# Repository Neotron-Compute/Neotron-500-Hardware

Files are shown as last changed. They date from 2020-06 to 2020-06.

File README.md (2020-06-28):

# Neotron 500

> A Neotron based home computer, powered by an 32-bit ARM Cortex-M7, with USB, Ethernet and hardware accelerated graphics.

## The top-level Specs

* 480 MHz 32-bit ARM Cortex-M7 CPU core
* 1024 KiB of internal ECC SRAM (used as VRAM and for OS buffers)
* 8 MiB external QuadSPI SRAM
* Super-VGA output
   * 640x480
   * 800x600
   * 256 colours from a pallette of 262,144
* 16-bit 48 kHz audio input and output (line-in, mic-in, line-out and headphone-out)
* Four high-speed (480 Mbps) USB 2.0 ports
   * Two USB A ports on-board
   * Header for additional two ports
* IEEE-1284 Parallel Port
* RS232 Port (five-wire)
* SD/MMC Slot
* PS/2 Keyboard and Mouse ports
* 2x Atari/Sega joystick ports
* IDE Interface for hard drive, Zip drive, LS-120 or CD-ROM
* Battery-backed Real-time Clock and CMOS RAM
* SPI and I2C based expansion bus

## Why 500?

We already had a Neotron 32 and a Neotron 1000, and this was somewhere inbetween the two. Plus it's roughly the performance of an Amiga 500.

## The detailed specs

### The Processor

The Neotron-500 uses an [STM32H753IIT6] microcontroller.

[STM32H753IIT6]: https://www.st.com/en/microcontrollers-microprocessors/stm32h753ii.html

```
STM32H753IIT6
vvvvv||vv|||+-- -40°C to +85°C
  |  ||| ||+-- LQFP Package
  |  ||| |+-- 2048 KiB Flash
  |  ||| +-- 176 pin
  |  ||+-- USB OTG FS/HS, Ethernet, LCD-TFT, Crypto
  |  |+-- Cortex-M7
  |  +-- High-performance family
  +-- 32-bit ARM Microcontroller from ST Micro
```

This microcontroller has:

* An ARM Cortex-M7F core
  * dual-issue, six-stage pipeline
  * hardware floating point
  * 16 KiB instruction cache
  * 16 KiB data cache  
* Clockspeed of up to 480 MHz
* 176 pins, in a low-profile quad flat package (LQFP)
* 2 MiB Flash
* 128 KiB tightly-coupled (Cortex-M only) data SRAM
* 64 KiB tightly-coupled (Cortex-M only) instruction SRAM
* 512 KiB of AXI-SRAM with ECC
* Further ECC SRAM banks of 128, 128, 64 and 32 KiB each
* 4 KiB of battery-backed SRAM
* External parallel memory bus interface with SDRAM support
* Memory-mapped 133 MHz QuadSPI interface
* MII/RMII 10/100 Ethernet MAC
* USB Full-speed (12 Mbps) OTG MAC/PHY
* USB High-speed (480 Mbps) OTG MAC
* 24-bit LCD-TFT interface with ChromART 2D video accelerator
* Hardware JPEG, random number generator, CRC and crypto
* RTC with 4 KiB battery backed RAM
* MIPI CSI Camera interface
* 2x SD/MMC controllers
* Multiple I2S audio in/out interfaces
* Multiple UART interfaces
* Multiple SPI bus interfaces
* Multiple I2C bus interfaces
* Multiple CAN bus interfaces

In terms of the CoreMark benchmark (and when running from internal Flash), this CPU is about the same speed as a Raspberry Pi Zero (despite running at just 40% of the clock speed), and somewhere around an 866 MHz Pentium III running from SDRAM. Running from external QuadSPI SRAM, however, is where we are down on performance. PC66 SDRAM has a peak of around 500 MiB/sec, and 32-bit 33.3 MHz DRAM is about 125 MiB/sec, whilst our QuadSPI SRAM is more like 40 MiB/sec. But I'm hoping it will run Doom.

### Memory Layout

We use:

* 128 KiB tightly-coupled data SRAM for the system stack and OS buffer.
* 64 KiB tightly-coupled instruction SRAM for OS routines.
* 128 KiB SRAM for DMA and device buffers.
* 512 KiB AXI-SRAM for video frame buffers.
  * 640x480 @ 8bpp = 300 KiB
  * 800x600 @ 8bpp = 468 KiB
* 4 KiB battery backed SRAM for system settings
* 512 KiB internal Flash for the Neotron BIOS
* 512 KiB internal Flash for Neotron OS
* 1024 KiB internal Flash for ROM-based user applications

You can either use external QSPI SRAM, or the second 128 KiB SRAM bank, for running user applications.

## The Motherboard

The Neotron 500 Motherboard is completely open-source hardware, and all the components are either through-hole parts that are easy to self install, or available from the [JLCPCB SMT assembly service].

The motherboard has:

* Regulated 5V Input
  * If you want to power four 500 mA USB devices from your Neotron 528ST, this needs to be capable at least 2.5A
  * TBD whether this is a DC barrel jack, full-size USB B, mini USB B or micro USB B
  * Or even take 5V from a 110V/240V IEC inlet PSU
  * Or we could take 6V-9V from a DC barrel jack and have an on-board 5V regulator
* Lyontek LY68L6400SLIT 8 MiB (8Mbit x 8) QuadSPI SRAM
  * 4-bit interface
  * 84 MHz clock rate (higher if we can configure the STM32 to avoid crossing page boundaries)
* Texas Instruments DP83848C 10/100 MII/RMII Ethernet PHY, and RJ45 Ethernet jack
  * MII Interface to the STM32
  * RJ45 100BASE-TX Ethernet jack
* Texas Instruments TLV320AIC23BPW Audio Codec
  * 16-bit 48 kHz I2S input and output to the STM32
  * Amplified stereo 3.5mm TRS headphone output
  * Line-level stereo 3.5mm TRS output
  * Line-level stereo 3.5mm TRS input
  * Mono microphone 3.5mm input
* Microchip USB3300 High-speed (480 Mbps) ULPI USB 2.0 PHY
* Microchip USB2514B High-speed (480 Mbps) four port USB 2.0 hub, with 2x2 USB 2.0 A ports.
* 18-bit (6-6-6) R2R DAC and 3PEAK HD video output buffer, with standard DE15HD VGA connector
* Full-size external-facing SD Card slot
* 2x PS/2 Ports for keyboard and mouse (2x mini-DIN 6-pin sockets)
* 2x 9-pin Atari Joystick/SEGA Genesis game-pad ports
* Power switch and reset switch
* MIDI In and Out ports (2x 5-pin DIN180 sockets)
* IEEE1284 Parallel Port (26-pin IDC box header as used on PCs)
* RS232 Port (five-wire, 10-pin IDC box header as used on PCs)
* 40-pin IDE interface
* Coin-cell for the STM32's real-time clock and battery-backed SRAM
* SPI and I2C based expansion bus (compatible with the Neotron 32)
* Additional QuadSPI expansion bus

[JLCPCB SMT assembly service]: https://jlcpcb.com/parts

Expected price is $40 for the motherboard with SMT parts loaded, and another $20 for the through-hole connectors

## Software

This system is designed to run the Neotron OS. To do that, it has a bespoke version of the Neotron BIOS. It is compatible with all 'well-behaved' Neotron applications that stick to the Neotron OS APIs rather than poking hardware directly.

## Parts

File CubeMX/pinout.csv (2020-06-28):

Position | Name | Type | Signal | Label
1 | PE2 | I/O | FMC_A23
2 | PE3 | I/O | FMC_A19
3 | PE4 | I/O | FMC_A20
4 | PE5 | I/O | FMC_A21
5 | PE6 | I/O | FMC_A22
6 | VBAT | Power
7 | PI8 | I/O
8 | PC13 | I/O
9 | PC14 | I/O | RCC_OSC32_IN
10 | PC15 | I/O | RCC_OSC32_OUT
11 | PI9 | I/O | LTDC_VSYNC
12 | PI10 | I/O | LTDC_HSYNC
13 | PI11 | I/O | USB_OTG_HS_ULPI_DIR
14 | VSS | Power
15 | VDD | Power
16 | PF0 | I/O | FMC_A0
17 | PF1 | I/O | FMC_A1
18 | PF2 | I/O | FMC_A2
19 | PF3 | I/O | FMC_A3
20 | PF4 | I/O | FMC_A4
21 | PF5 | I/O | FMC_A5
22 | VSS | Power
23 | VDD | Power
24 | PF6 | I/O | QUADSPI_BK1_IO3
25 | PF7 | I/O | QUADSPI_BK1_IO2
26 | PF8 | I/O | QUADSPI_BK1_IO0
27 | PF9 | I/O | QUADSPI_BK1_IO1
28 | PF10 | I/O | LTDC_DE
29 | PH0 | I/O | RCC_OSC_IN
30 | PH1 | I/O | RCC_OSC_OUT
31 | NRST | Reset
32 | PC0 | I/O | USB_OTG_HS_ULPI_STP
33 | PC1 | I/O | ETH_MDC
34 | PC2_C | I/O | I2S2_SDI
35 | PC3_C | I/O | USB_OTG_HS_ULPI_NXT
36 | VDD | Power
37 | VSSA | Power
38 | VREF+ | MonoIO
39 | VDDA | Power
40 | PA0 | I/O | SDMMC2_CMD
41 | PA1 | I/O | ETH_REF_CLK
42 | PA2 | I/O | ETH_MDIO
43 | PH2 | I/O | QUADSPI_BK2_IO0
44 | PH3 | I/O | QUADSPI_BK2_IO1
45 | PH4 | I/O | LTDC_G5
46 | PH5 | I/O
47 | PA3 | I/O | USB_OTG_HS_ULPI_D0
48 | VSS | Power
49 | VDD | Power
50 | PA4 | I/O | USB_OTG_HS_SOF
51 | PA5 | I/O | USB_OTG_HS_ULPI_CK
52 | PA6 | I/O | MDIOS_MDC
53 | PA7 | I/O | ETH_CRS_DV
54 | PC4 | I/O | ETH_RXD0
55 | PC5 | I/O | ETH_RXD1
56 | PB0 | I/O | USB_OTG_HS_ULPI_D1
57 | PB1 | I/O | USB_OTG_HS_ULPI_D2
58 | PB2 | I/O | QUADSPI_CLK
59 | PF11 | I/O | SPI5_MOSI
60 | PF12 | I/O | FMC_A6
61 | VSS | Power
62 | VDD | Power
63 | PF13 | I/O | FMC_A7
64 | PF14 | I/O | FMC_A8
65 | PF15 | I/O | FMC_A9
66 | PG0 | I/O | FMC_A10
67 | PG1 | I/O | FMC_A11
68 | PE7 | I/O | FMC_D4
69 | PE8 | I/O | FMC_D5
70 | PE9 | I/O | FMC_D6
71 | VSS | Power
72 | VDD | Power
73 | PE10 | I/O | FMC_D7
74 | PE11 | I/O | FMC_D8
75 | PE12 | I/O | FMC_D9
76 | PE13 | I/O | FMC_D10
77 | PE14 | I/O | FMC_D11
78 | PE15 | I/O | FMC_D12
79 | PB10 | I/O | USB_OTG_HS_ULPI_D3
80 | PB11 | I/O | USB_OTG_HS_ULPI_D4
81 | VCAP | Power
82 | VDD | Power
83 | PH6 | I/O | SPI5_SCK
84 | PH7 | I/O | SPI5_MISO
85 | PH8 | I/O | LTDC_R2
86 | PH9 | I/O | LTDC_R3
87 | PH10 | I/O | LTDC_R4
88 | PH11 | I/O | LTDC_R5
89 | PH12 | I/O | LTDC_R6
90 | VSS | Power
91 | VDD | Power
92 | PB12 | I/O | USB_OTG_HS_ULPI_D5
93 | PB13 | I/O | USB_OTG_HS_ULPI_D6
94 | PB14 | I/O | SDMMC2_D0
95 | PB15 | I/O | SDMMC2_D1
96 | PD8 | I/O | FMC_D13
97 | PD9 | I/O | FMC_D14
98 | PD10 | I/O | FMC_D15
99 | PD11 | I/O | FMC_A16
100 | PD12 | I/O | FMC_A17
101 | PD13 | I/O | FMC_A18
102 | VSS | Power
103 | VDD | Power
104 | PD14 | I/O | FMC_D0
105 | PD15 | I/O | FMC_D1
106 | PG2 | I/O | FMC_A12
107 | PG3 | I/O | FMC_A13
108 | PG4 | I/O | FMC_A14
109 | PG5 | I/O | FMC_A15
110 | PG6 | I/O | LTDC_R7
111 | PG7 | I/O | LTDC_CLK
112 | PG8 | I/O | LTDC_G7
113 | VSS | Power
114 | VDD33_USB | Power
115 | PC6 | I/O | I2S2_MCK
116 | PC7 | I/O | FMC_NE1
117 | PC8 | I/O | UART5_RTS
118 | PC9 | I/O | UART5_CTS
119 | PA8 | I/O | LTDC_B3
120 | PA9 | I/O | I2S2_CK
121 | PA10 | I/O | MDIOS_MDIO
122 | PA11 | I/O | USB_OTG_FS_DM
123 | PA12 | I/O | USB_OTG_FS_DP
124 | PA13 | I/O | DEBUG_JTMS-SWDIO
125 | VCAP | Power
126 | VSS | Power
127 | VDD | Power
128 | PH13 | I/O | LTDC_G2
129 | PH14 | I/O | LTDC_G3
130 | PH15 | I/O | LTDC_G4
131 | PI0 | I/O
132 | PI1 | I/O | LTDC_G6
133 | PI2 | I/O
134 | PI3 | I/O | I2S2_SDO
135 | VSS | Power
136 | VDD | Power
137 | PA14 | I/O | DEBUG_JTCK-SWCLK
138 | PA15 | I/O
139 | PC10 | I/O
140 | PC11 | I/O | QUADSPI_BK2_NCS
141 | PC12 | I/O | UART5_TX
142 | PD0 | I/O | FMC_D2
143 | PD1 | I/O | FMC_D3
144 | PD2 | I/O | UART5_RX
145 | PD3 | I/O
146 | PD4 | I/O | FMC_NOE
147 | PD5 | I/O | FMC_NWE
148 | VSS | Power
149 | VDD | Power
150 | PD6 | I/O | SDMMC2_CK
151 | PD7 | I/O
152 | PG9 | I/O | QUADSPI_BK2_IO2
153 | PG10 | I/O | LTDC_B2
154 | PG11 | I/O | ETH_TX_EN
155 | PG12 | I/O | ETH_TXD1
156 | PG13 | I/O | ETH_TXD0
157 | PG14 | I/O | QUADSPI_BK2_IO3
158 | VSS | Power
159 | VDD | Power
160 | PG15 | I/O
161 | PB3 | I/O | SDMMC2_D2
162 | PB4 | I/O | SDMMC2_D3
163 | PB5 | I/O | USB_OTG_HS_ULPI_D7
164 | PB6 | I/O | QUADSPI_BK1_NCS
165 | PB7 | I/O | I2C1_SDA
166 | BOOT0 | Boot
167 | PB8 | I/O | I2C1_SCL
168 | PB9 | I/O | I2S2_WS
169 | PE0 | I/O | FMC_NBL0
170 | PE1 | I/O | FMC_NBL1
171 | PDR_ON | Reset
172 | VDD | Power
173 | PI4 | I/O | LTDC_B4
174 | PI5 | I/O | LTDC_B5
175 | PI6 | I/O | LTDC_B6
176 | PI7 | I/O | LTDC_B7

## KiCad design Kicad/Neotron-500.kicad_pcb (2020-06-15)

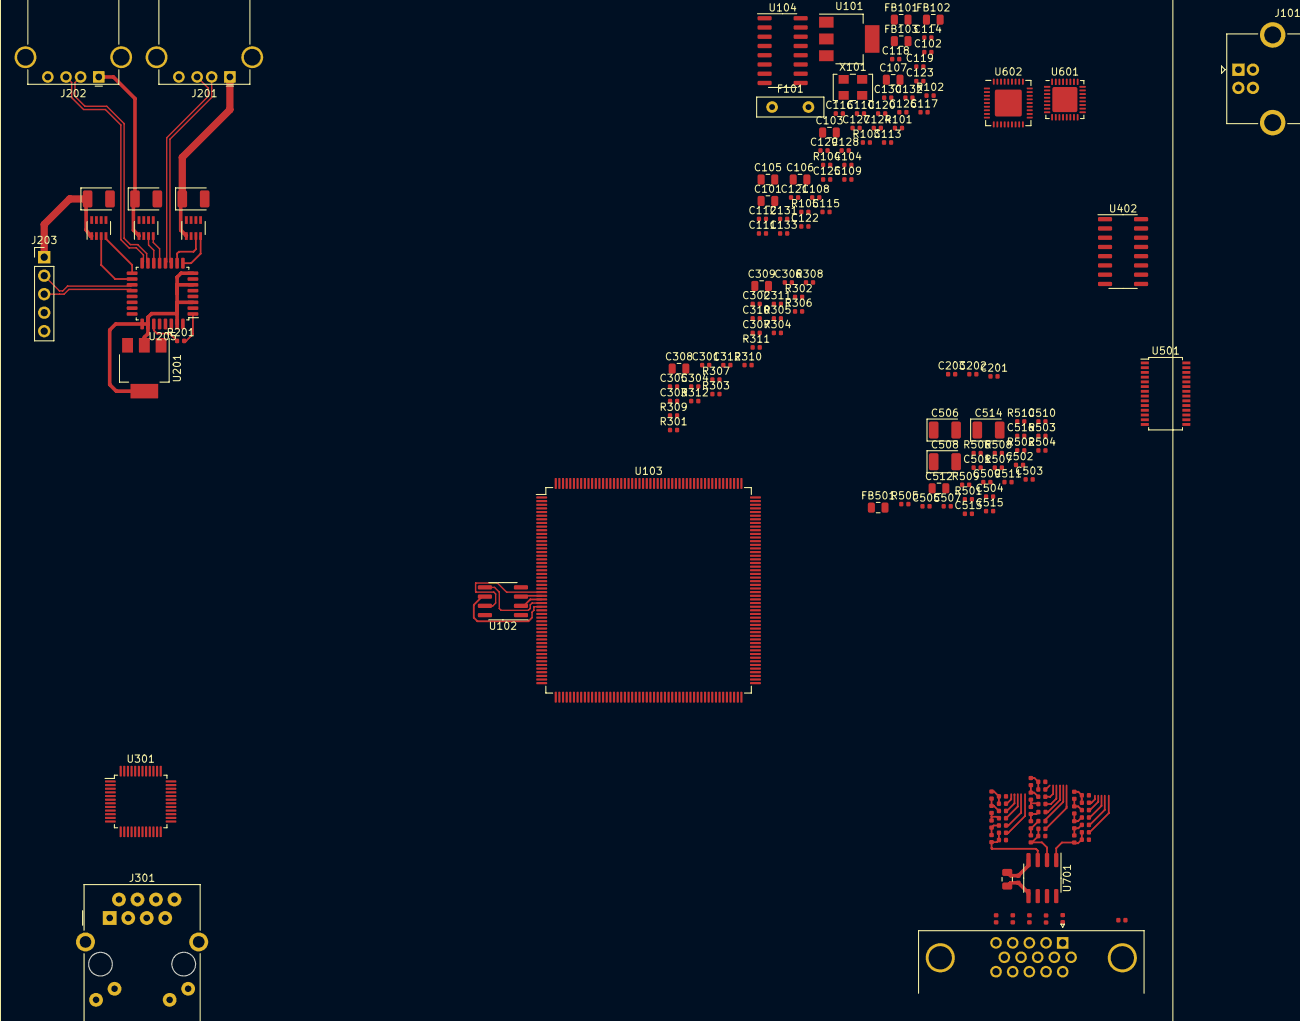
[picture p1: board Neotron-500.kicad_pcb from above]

Board: 2 copper layers, 165 parts (0 on the bottom side), 125 nets.

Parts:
C101, C103, C105: 22u; C_0805_2012Metric
C102, C104, C108, C113, C115, C117, C119, C120, C121, C122, C123, C124, C125, C126, C128, C129, C130, C131, C132, C133, C201, C301, C302, C303, C304, C305, C306, C307, C310, C311, C312, C511, C513, C702: 100n; C_0402_1005Metric
C106, C107: 2.2u; C_0805_2012Metric
C109, C110, C111, C112: 9p; C_0402_1005Metric
C114, C116, C118, C127, C501, C502, C504, C505, C509: 1u; C_0402_1005Metric
C202, C203: 4.7u; C_0402_1005Metric
C204, C205, C206, C506, C508, C514: 100u; CP_EIA-3528-21_Kemet-B
C308, C309, C512: 10u; C_0805_2012Metric
C503, C507, C510: 47p; C_0402_1005Metric
C515, C516: 27p; C_0402_1005Metric
C701: 4.7u; C_0805_2012Metric
F101: 2.5A; C_Disc_D9.0mm_W2.5mm_P5.00mm
FB101, FB102, FB103, FB501: 100R@100MHz; L_0805_2012Metric
J101: USB_B; USB_B_OST_USB-B1HSxx_Horizontal
J201, J202: USB_A; USB_A_Stewart_SS-52100-001_Horizontal
J203: USB_A; PinHeader_1x05_P2.54mm_Vertical
J301: RJ45_Amphenol_RJMG1BD3B8K1ANR
J701: DB15_Female_HighDensity_MountingHoles; DSUB-15-HD_Female_Horizontal_P2.29x1.98mm_EdgePinOffset3.03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
R101, R102, R103, R312: 0R; R_0402_1005Metric
R104, R105: 10k; R_0402_1005Metric
R201: 1.5k; R_0402_1005Metric
R301, R302, R305, R307: 49.9R; R_0402_1005Metric
R303, R304, R306, R310: 2k2; R_0402_1005Metric
R308, R309: 1k; R_0402_1005Metric
R311: 4.87K; R_0402_1005Metric
R501: 2.2k; R_0402_1005Metric
R502, R503, R506, R507: 100k; R_0402_1005Metric
R504, R508: 4.99k; R_0402_1005Metric
R505, R509: 5k; R_0402_1005Metric
R510: 3R3; R_0402_1005Metric
R701, R702, R703, R704, R705, R711, R717, R718, R719, R720, R721, R722, R729, R731, R732, R733, R734, R735, R740: 24K; R_0402_1005Metric
R706, R707, R708, R709, R724, R725, R726, R727, R728, R736, R737, R738, R739: 12K; R_0402_1005Metric
R710, R730, R741: 3K3; R_0402_1005Metric
R712, R713, R714: 75; R_0402_1005Metric
R715, R716: 470; R_0402_1005Metric
R723: 0; R_0402_1005Metric
U101, U201: AMS1117-3.3; SOT-223-3_TabPin2
U102: LY68S3200SLT; SOIC-8_3.9x4.9mm_P1.27mm
U103: STM32F767BGTx; LQFP-208_28x28mm_P0.5mm
U104: MAX232; SOIC-16_3.9x9.9mm_P1.27mm
U202, U203, U204: AAT4610BIGV-1-T1; SOT-23-8
U205: TUSB2036; LQFP-32_7x7mm_P0.8mm
U301: DP83848C; LQFP-48_7x7mm_P0.5mm
U402: 74LS138; SOIC-16_3.9x9.9mm_P1.27mm
U501: TLV320AIC23BPW; TSSOP-28_4.4x9.7mm_P0.65mm
U601: USB3300-EZK; QFN-32-1EP_5x5mm_P0.5mm_EP3.45x3.45mm
U602: USB2514B_Bi; QFN-36-1EP_6x6mm_P0.5mm_EP3.7x3.7mm
U701: TPF133A; SOIC-8_3.9x4.9mm_P1.27mm
X101: 50MHz XO; Oscillator_SMD_TXC_7C-4Pin_5.0x3.2mm

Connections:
+3V3: C108.1, C301.1, C302.1, C303.1, C304.1, C511.1, C512.1, C701.1, C702.1, FB501.1, J301.R4, J301.R5, R301.2, R302.1, R305.2, R306.1, R307.1, R308.2, R309.2, R310.1, R312.2, U102.8, U301.22, U301.32, U301.48, U501.1, U501.22, U501.27, U701.4, X101.1, X101.4
+5V: C101.1, C104.1, C105.1, C201.1, C202.1, F101.1, U101.3, U201.3, U202.5, U203.5, U204.5
/Audio/HEADPHONE_L: C506.1, U501.9
/Audio/HEADPHONE_R: C508.1, U501.10
/Audio/LINE_IN_L: C505.1, U501.20
/Audio/LINE_IN_R: C509.1, U501.19
/Audio/LINE_OUT_L: C502.1, U501.12
/Audio/LINE_OUT_R: C504.1, U501.13
/Audio/MIC_IN: C501.1, U501.18
/Audio/VDD_AUDIO: C513.1, C514.1, FB501.2, R510.2, U501.8
/Audio/V_MICBIAS: R501.1, U501.17
/Ethernet PHY/LED_ACT: J301.L2, U301.26
/Ethernet PHY/LED_SPEED: J301.L3, U301.27
/LTDC_B3: R731.1, U103.110
/LTDC_B4: R732.1, U103.144
/LTDC_B5: R733.1, U103.187
/LTDC_B6: R734.1, U103.188
/LTDC_B7: R735.1, U103.189
/LTDC_G2: R717.1, U103.55
/LTDC_G3: R718.1, U103.85
/LTDC_G4: R719.1, U103.123
/LTDC_G5: R720.1, U103.126
/LTDC_G6: R721.1, U103.127
/LTDC_G7: R722.1, U103.128
/LTDC_HSYNC: R715.2, U103.12
/LTDC_R3: R701.1, U103.67
/LTDC_R4: R702.1, U103.68
/LTDC_R5: R703.1, U103.69
/LTDC_R6: R704.1, U103.95
/LTDC_R7: R705.1, U103.65
/LTDC_VSYNC: R716.2, U103.11
/QUADSPI_BK1_IO0: U102.2, U103.29
/QUADSPI_BK1_IO1: U102.5, U103.30
/QUADSPI_BK1_IO2: U102.3, U103.28
/QUADSPI_BK1_IO3: U102.7, U103.27
/QUADSPI_BK1_NCS: U102.1, U103.195
/QUADSPI_CLK: U102.6, U103.31
/RCC_OSC32_IN: C111.1, U103.9
/RCC_OSC32_OUT: C112.1, U103.10
/RCC_OSC_IN: C109.1, U103.32
/RCC_OSC_OUT: C110.1, U103.33
/USB 1.1 Host/HUB_3V3: C203.1, U201.2, U205.3, U205.6, U205.8, U205.25, U205.26, U205.31
/USB 1.1 Host/PORT1_D+: J201.3, U205.12
/USB 1.1 Host/PORT1_D-: J201.2, U205.11
/USB 1.1 Host/PORT2_D+: J202.3, U205.16
/USB 1.1 Host/PORT2_D-: J202.2, U205.15
/USB 1.1 Host/PORT3_D+: J203.3, U205.20
/USB 1.1 Host/PORT3_D-: J203.2, U205.19
/USB 1.1 Host/~PORT1_EN: U202.4, U205.9
/USB 1.1 Host/~PORT1_OC: U202.3, U205.10
/USB 1.1 Host/~PORT2_EN: U203.4, U205.13
/USB 1.1 Host/~PORT2_OC: U203.3, U205.14
/USB 1.1 Host/~PORT3_EN: U204.4, U205.17
/USB 1.1 Host/~PORT3_OC: U204.3, U205.18
/USB_OTG_HS_D+: R201.2, U205.1
/VDDA: C115.1, C116.1, FB101.2, R101.2, U103.42
/VDD_MCU: C102.1, C103.1, C119.1, C120.1, C121.1, C122.1, C123.1, C124.1, C125.1, C128.1, C129.1, C130.1, C131.1, C132.1, C133.1, FB101.1, R102.2, R103.2, U101.2, U103.15, U103.26, U103.39, U103.52, U103.59, U103.73, U103.83, U103.94, U103.103, U103.115, U103.124, U103.150, U103.158, U103.185, U103.204
/VDD_SDMMC: C126.1, C127.1, R102.1, U103.171
/VDD_USB: C117.1, C118.1, R103.1, U103.137
/VGA Video Output/ANALOG_BLUE: R735.2, R739.1, R741.1, U701.3
/VGA Video Output/ANALOG_GREEN: R722.2, R728.1, R730.1, U701.2
/VGA Video Output/ANALOG_RED: R705.2, R709.1, R710.1, U701.1
/VGA Video Output/BOUT: R714.1, U701.6
/VGA Video Output/GOUT: R713.1, U701.7
/VGA Video Output/ROUT: R712.1, U701.8
/VREF+: C113.1, C114.1, R101.1, U103.41
GND: C101.2, C102.2, C103.2, C104.2, C105.2, C106.2, C107.2, C108.2, C109.2, C110.2, C111.2, C112.2, C113.2, C114.2, C115.2, C116.2, C117.2, C118.2, C119.2, C120.2, C121.2, C122.2, C123.2, C124.2, C125.2, C126.2, C127.2, C128.2, C129.2, C130.2, C131.2, C132.2, C133.2, C201.2, C202.2, C203.2, C204.2, C205.2, C206.2, C301.2, C302.2, C303.2, C304.2, C305.2, C306.2, C307.2, C308.2, C309.2, C310.2, C311.2, C312.2, C511.2, C512.2, C513.2, C514.2, C515.2, C516.2, C701.2, C702.2, FB103.1, J101.4, J201.4, J201.5, J202.4, J202.5, J203.4, J203.5, J301.13, J301.R8, J701.5, J701.6, J701.7, J701.8, R104.2, R303.2, R304.2, R311.1, R710.2, R711.2, R723.2, R729.2, R730.2, R740.2, R741.2, U101.1, U102.4, U103.14, U103.25, U103.40, U103.51, U103.60, U103.72, U103.82, U103.93, U103.114, U103.125, U103.136, U103.149, U103.170, U103.184, U103.202, U201.1, U202.2, U203.2, U204.2, U205.7, U205.21, U205.22, U205.23, U205.24, U205.28, U301.15, U301.19, U301.35, U301.36, U301.47, U501.28, U701.5, X101.2
GNDA: C503.2, C507.2, C510.2, R502.1, R503.1, R505.1, R506.1, R507.1, R509.1, U501.11, U501.15
unnamed: C106.1, U103.92
unnamed: C107.1, U103.148
unnamed: C204.1, J201.1, U202.1
unnamed: C205.1, J202.1, U203.1
unnamed: C206.1, J203.1, U204.1
unnamed: C305.1, U301.37
unnamed: C306.1, U301.18
unnamed: C307.1, C308.1, U301.23
unnamed: C309.1, C310.1, C311.1, C312.1, R312.1
unnamed: C501.2, C503.1, R501.2
unnamed: C502.2, R502.2
unnamed: C504.2, R503.2
unnamed: C505.2, C507.1, R504.1, R505.2
unnamed: C506.2, R506.2
unnamed: C508.2, R507.2
unnamed: C509.2, C510.1, R508.1, R509.2
unnamed: C515.1, U501.25
unnamed: C516.1, U501.26
unnamed: F101.2, FB102.2
unnamed: FB102.1, J101.1
unnamed: FB103.2, J101.5
unnamed: J301.L1, R309.1
unnamed: J301.L4, R308.1
unnamed: J301.R1, R301.1, U301.17
unnamed: J301.R2, R302.2, U301.16
unnamed: J301.R3, R305.1, U301.14
unnamed: J301.R6, R307.2, U301.13
unnamed: J701.0, R723.1
unnamed: J701.1, R712.2
unnamed: J701.2, R713.2
unnamed: J701.3, R714.2
unnamed: J701.13, R715.1
unnamed: J701.14, R716.1
unnamed: R104.1, U103.203
unnamed: R105.1, U103.197
unnamed: R201.1, U205.27
unnamed: R303.1, U301.5
unnamed: R304.1, U301.6
unnamed: R306.2, U301.39
unnamed: R310.2, U301.7
unnamed: R311.2, U301.24
unnamed: R510.1, U501.14
unnamed: R701.2, R706.2, R711.1
unnamed: R702.2, R706.1, R707.2
unnamed: R703.2, R707.1, R708.2
unnamed: R704.2, R708.1, R709.2
unnamed: R717.2, R724.2, R729.1
unnamed: R718.2, R724.1, R725.2
unnamed: R719.2, R725.1, R726.2
unnamed: R720.2, R726.1, R727.2
unnamed: R721.2, R727.1, R728.2
unnamed: R731.2, R736.2, R740.1
unnamed: R732.2, R736.1, R737.2
unnamed: R733.2, R737.1, R738.2
unnamed: R734.2, R738.1, R739.2
unnamed: U601.7, U602.31
unnamed: U601.8, U602.30

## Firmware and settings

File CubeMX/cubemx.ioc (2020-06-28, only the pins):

PH12.Signal=LTDC_R6
PG4.Signal=FMC_A14_BA0
PG8.Signal=LTDC_G7
PC12.Signal=UART5_TX
PG0.Signal=FMC_A10
PB13.Signal=USB_OTG_HS_ULPI_D6
PG13.Signal=ETH_TXD0
PF7.Signal=QUADSPI_BK1_IO2
PH9.Signal=LTDC_R3
PD4.Signal=FMC_NOE
PB6.Signal=QUADSPI_BK1_NCS
PC7.Signal=FMC_NE1
PD0.Signal=FMC_D2_DA2
PD8.Signal=FMC_D13_DA13
PE5.Signal=FMC_A21
PE1.Signal=FMC_NBL1
PB2.Signal=QUADSPI_CLK
PE9.Signal=FMC_D6_DA6
PI6.Signal=LTDC_B6
PI3.Signal=I2S2_SDO
PE2.Signal=FMC_A23
PA8.Signal=LTDC_B3
PF3.Signal=FMC_A3
PE10.Signal=FMC_D7_DA7
PA0.Signal=SDMMC2_CMD
PB9.Signal=I2S2_WS
PB1.Signal=USB_OTG_HS_ULPI_D2
PD12.Signal=FMC_A17_ALE
PA10.Signal=MDIOS_MDIO
PH2.Signal=QUADSPI_BK2_IO0
PF14.Signal=FMC_A8
PI11.Signal=USB_OTG_HS_ULPI_DIR
PD15.Signal=FMC_D1_DA1
PG12.Signal=ETH_TXD1
PH15.Signal=LTDC_G4
PH13.Signal=LTDC_G2
PG5.Signal=FMC_A15_BA1
PG9.Signal=QUADSPI_BK2_IO2
PC6.Signal=I2S2_MCK
PD1.Signal=FMC_D3_DA3
PC0.Signal=USB_OTG_HS_ULPI_STP
PG10.Signal=LTDC_B2
PD10.Signal=FMC_D15_DA15
PA9.Signal=I2S2_CK
PB10.Signal=USB_OTG_HS_ULPI_D3
PB14.Signal=SDMMC2_D0
PA5.Signal=USB_OTG_HS_ULPI_CK
PI7.Signal=LTDC_B7
PE14.Signal=FMC_D11_DA11
PE15.Signal=FMC_D12_DA12
PE8.Signal=FMC_D5_DA5
PI1.Signal=LTDC_G6
PF13.Signal=FMC_A7
PA4.Signal=USB_OTG_HS_SOF
PB5.Signal=USB_OTG_HS_ULPI_D7
PD11.Signal=FMC_A16_CLE
PA11.Signal=USB_OTG_FS_DM
PH6.Signal=SPI5_SCK
PF9.Signal=QUADSPI_BK1_IO1
PE3.Signal=FMC_A19
PF4.Signal=FMC_A4
PD2.Signal=UART5_RX
PB0.Signal=USB_OTG_HS_ULPI_D1
PC1.Signal=ETH_MDC
PG6.Signal=LTDC_R7
Mcu.UserName=STM32H753IITx
PH14.Signal=LTDC_G3
PH10.Signal=LTDC_R4
PG2.Signal=FMC_A12
PB11.Signal=USB_OTG_HS_ULPI_D4
PB15.Signal=SDMMC2_D1
PG11.Signal=ETH_TX_EN
PD13.Signal=FMC_A18
PA12.Signal=USB_OTG_FS_DP
PF12.Signal=FMC_A6
PC2_C.Signal=I2S2_SDI
PE13.Signal=FMC_D10_DA10
PI5.Signal=LTDC_B5
PF11.Signal=SPI5_MOSI
PB7.Signal=I2C1_SDA
PE4.Signal=FMC_A20
PA6.Signal=MDIOS_MDC
PF8.Signal=QUADSPI_BK1_IO0
PF5.Signal=FMC_A5
PH7.Signal=SPI5_MISO
PF0.Signal=FMC_A0
PC5.Signal=ETH_RXD1
PE7.Signal=FMC_D4_DA4
PD6.Signal=SDMMC2_CK
PA3.Signal=USB_OTG_HS_ULPI_D0
PG7.Signal=LTDC_CLK
PH11.Signal=LTDC_R5
PG3.Signal=FMC_A13
PG1.Signal=FMC_A11
PC11.Signal=QUADSPI_BK2_NCS
PC8.Signal=UART5_RTS
PC4.Signal=ETH_RXD0
PI10.Signal=LTDC_HSYNC
PD9.Signal=FMC_D14_DA14
PD5.Signal=FMC_NWE
PH4.Signal=LTDC_G5
PF6.Signal=QUADSPI_BK1_IO3
PH8.Signal=LTDC_R2
PF2.Signal=FMC_A2
PE11.Signal=FMC_D8_DA8
PA1.Signal=ETH_REF_CLK
PG14.Signal=QUADSPI_BK2_IO3
PI9.Signal=LTDC_VSYNC
PF10.Signal=LTDC_DE
PI4.Signal=LTDC_B4
PF15.Signal=FMC_A9
PF1.Signal=FMC_A1
PE6.Signal=FMC_A22
PE0.Signal=FMC_NBL0
PE12.Signal=FMC_D9_DA9
PA2.Signal=ETH_MDIO
PD14.Signal=FMC_D0_DA0
PH3.Signal=QUADSPI_BK2_IO1
PC3_C.Signal=USB_OTG_HS_ULPI_NXT
PB8.Signal=I2C1_SCL
PC9.Signal=UART5_CTS
PB12.Signal=USB_OTG_HS_ULPI_D5
PA7.Signal=ETH_CRS_DV

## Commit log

2020-05-30 First pass with 208 pin chip.
    [NeotronH7.kicad_pcb, NeotronH7.sch, audio.sch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]
2020-05-30 Rename kicad folder
    [NeotronF7.kicad_pcb, NeotronF7.sch, audio.sch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]
2020-06-01 Swap Flash for ESP-PSRAM as it's closer to the part we actually want.
    [NeotronF7.sch]
2020-06-05 Work in progress
    [NeotronF7.sch, audio.sch, cpu.sch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]
2020-06-09 Adding VGA output buffer/filter.
    [NeotronF7.sch, usb2hub.sch, vga.sch]
2020-06-13 Renamed to Neotron-528ST
    [Neotron-528ST.kicad_pcb, Neotron-528ST.sch, vga.sch]
2020-06-15 Removed USB FS hub. Added stacked USB A connector.
    [Neotron-528ST.kicad_pcb, Neotron-528ST.sch, audio.sch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]
2020-06-28 Switched over to H7
    [pinout.csv]
2020-06-28 Renamed KiCad files.
    [Neotron-500.kicad_pcb, Neotron-500.sch]
2020-06-28 Swap to H7 in the Schematic
    [Neotron-500.sch, pinout.csv, usb2hub.sch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]

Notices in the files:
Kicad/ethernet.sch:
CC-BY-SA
